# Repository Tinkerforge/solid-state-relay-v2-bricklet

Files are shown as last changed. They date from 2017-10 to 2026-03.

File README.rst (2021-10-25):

Solid State Relay Bricklet 2.0
==============================

This repository contains the firmware source code and the hardware design
files. The documentation generator configs can be found at
https://github.com/Tinkerforge/generators

Repository Content
------------------

software/:
 * examples/: Examples for all supported languages
 * build/: Compiled files
 * src/: Source code of firmware
 * Makefile: Makefile to build project

hardware/:
 * Contains KiCad project files and additionally schematics as PDF

datasheets/:
 * Contains datasheets for sensors and complex ICs that are used

Hardware
--------

The hardware is designed with the open source EDA Suite KiCad
(http://www.kicad.org). Before you are able to open the files,
you have to install the Tinkerforge kicad-libraries
(https://github.com/Tinkerforge/kicad-libraries). You can either clone
them directly in hardware/ or clone them in a separate folder and
symlink them into hardware/
(ln -s kicad_path/kicad-libraries project_path/hardware). After that you
can open the .pro file in hardware/ with KiCad and from there view and
modify the schematics and the PCB layout.

Software
--------

If you want to do your own Brick/Bricklet firmware development we highly
recommend that you use our build environment setup script and read the
tutorial (https://www.tinkerforge.com/en/doc/Tutorials/Tutorial_Build_Environment/Tutorial.html).

To compile the C code we recommend you to install the newest GNU Arm Embedded
Toolchain (https://launchpad.net/gcc-arm-embedded/+download).
You also need to install bricklib2 (https://github.com/Tinkerforge/bricklib2).

You can either clone it directly in software/src/ or clone it in a
separate folder and symlink it into software/src/
(ln -s bricklib_path/bricklib2 project_path/software/src/). Finally make sure to
have CMake installed (http://www.cmake.org/cmake/resources/software.html).

After that you can build the firmware by invoking make in software/.
The firmware (.zbin) can then be found in software/build/ and uploaded
with brickv (click button "Flashing" on start screen).

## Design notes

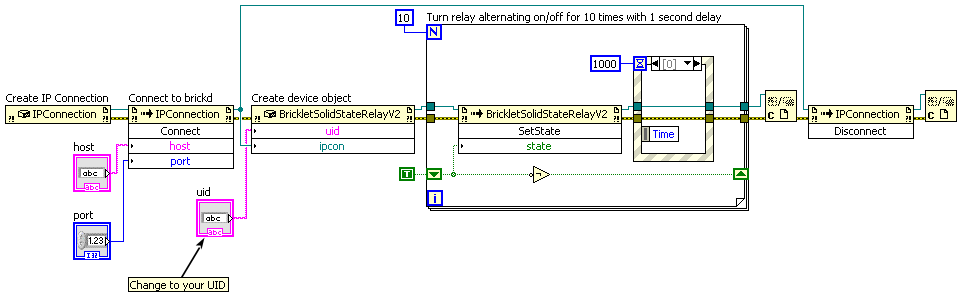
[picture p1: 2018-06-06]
software/examples/labview/Example Simple.vi.png

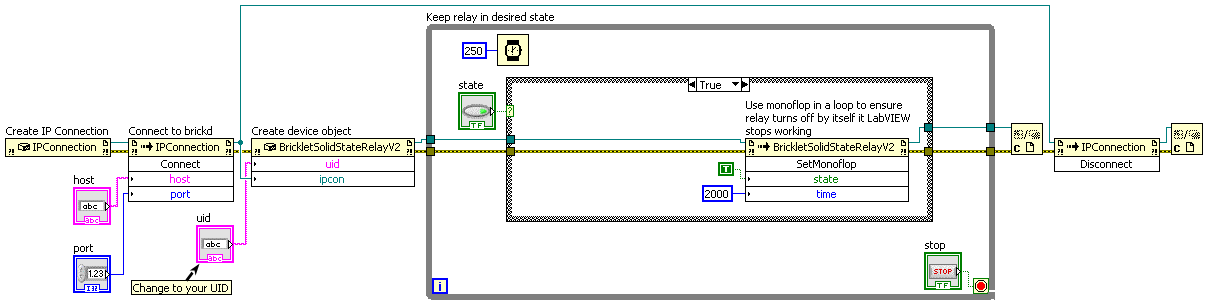
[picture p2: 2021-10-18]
software/examples/labview/Example Monoflop.vi.png

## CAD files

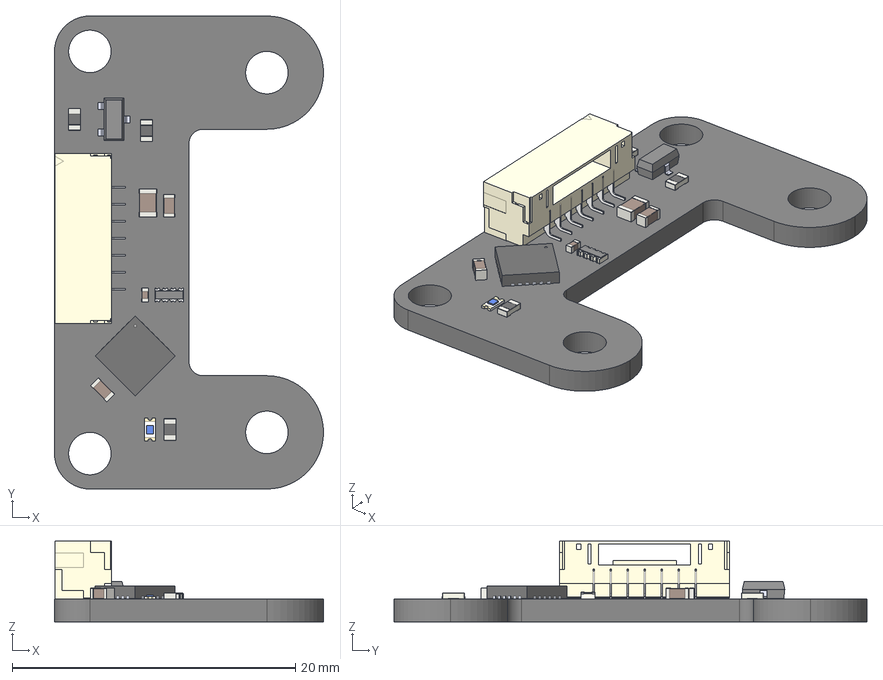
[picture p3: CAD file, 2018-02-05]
hardware/solid-state-relay-v2.step
19.0 x 33.4 x 5.70 mm

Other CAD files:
hardware/solid-state-relay-v2.FCStd

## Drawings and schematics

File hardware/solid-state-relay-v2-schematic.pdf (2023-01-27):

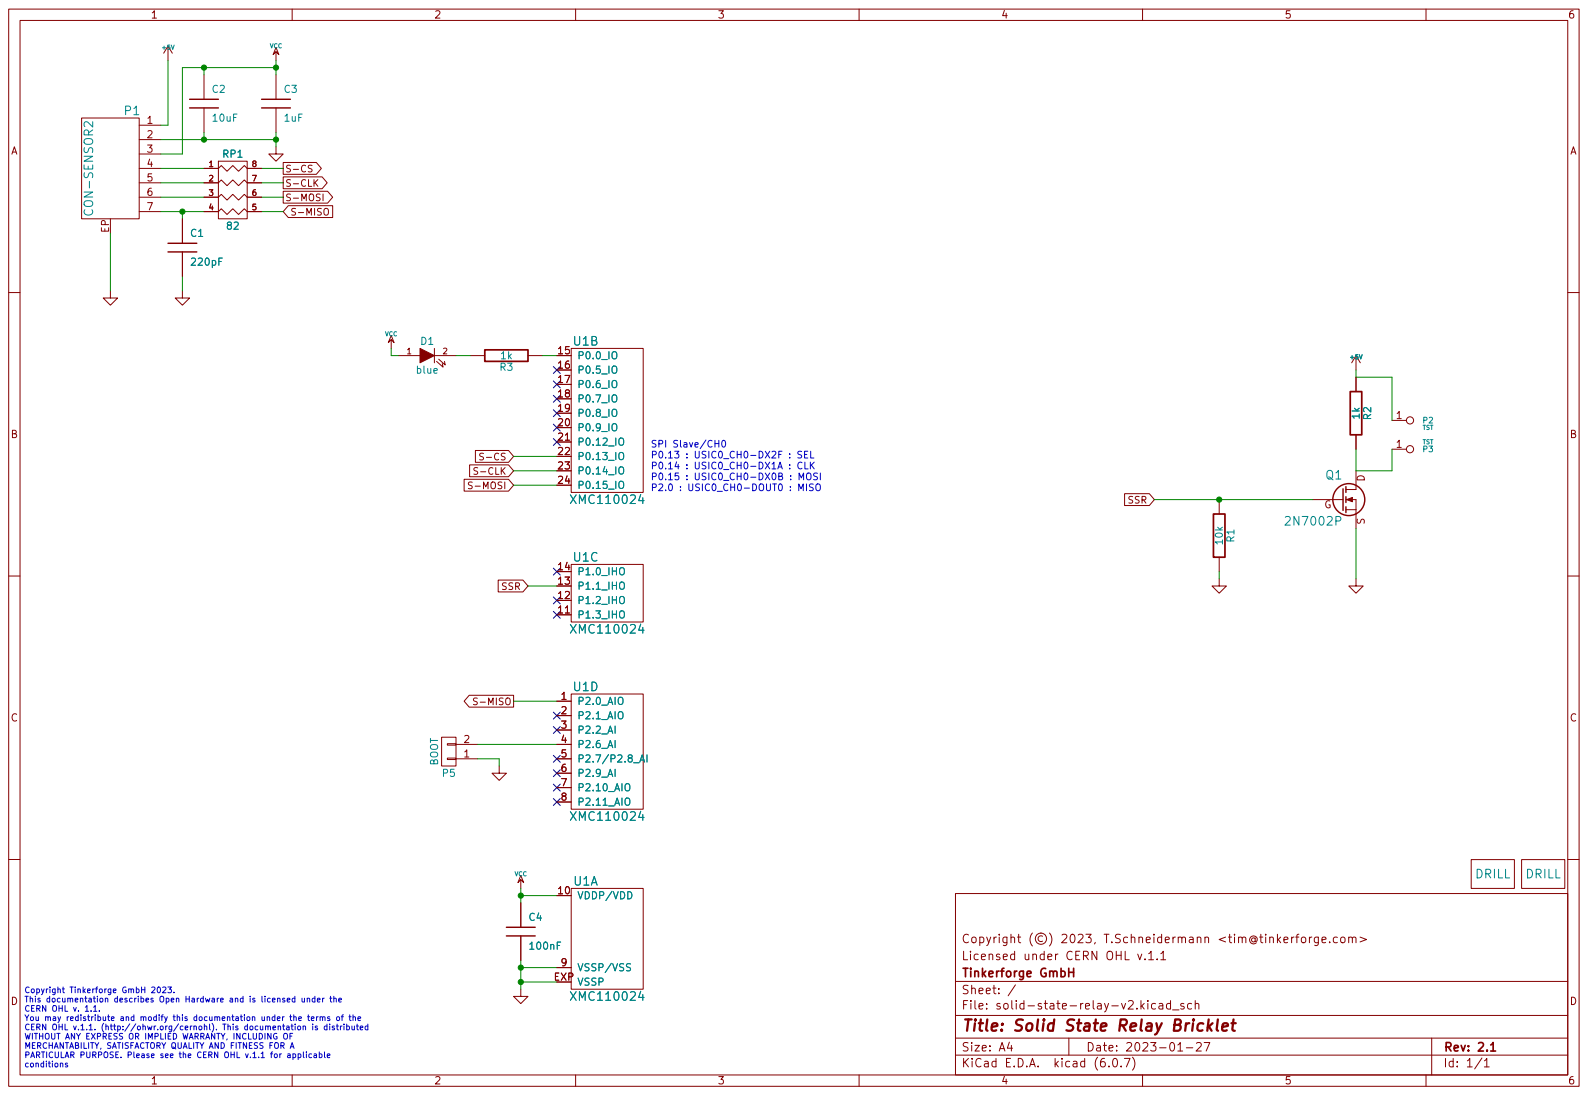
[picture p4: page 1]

SPI Slave/CH0 P0.13 : USIC0_CH0-DX2F : SEL P0.14 : USIC0_CH0-DX1A : CLK

Licensed under CERN OHL v.1.1
File: solid-state-relay-v2.kicad_sch Sheet: / Tinkerforge GmbH

Copyright Tinkerforge GmbH 2023. This documentation describes Open Hardware and is licensed under the CERN OHL v. 1.1. You may redistribute and modify this documentation under the terms of the CERN OHL v.1.1. (http://ohwr.org/cernohl). This documentation is distributed WITHOUT ANY EXPRESS OR IMPLIED WARRANTY, INCLUDING OF MERCHANTABILITY, SATISFACTORY QUALITY AND FITNESS FOR A

Id: 1/1 Title: Solid State Relay Bricklet

PARTICULAR PURPOSE. Please see the CERN OHL v.1.1 for applicable

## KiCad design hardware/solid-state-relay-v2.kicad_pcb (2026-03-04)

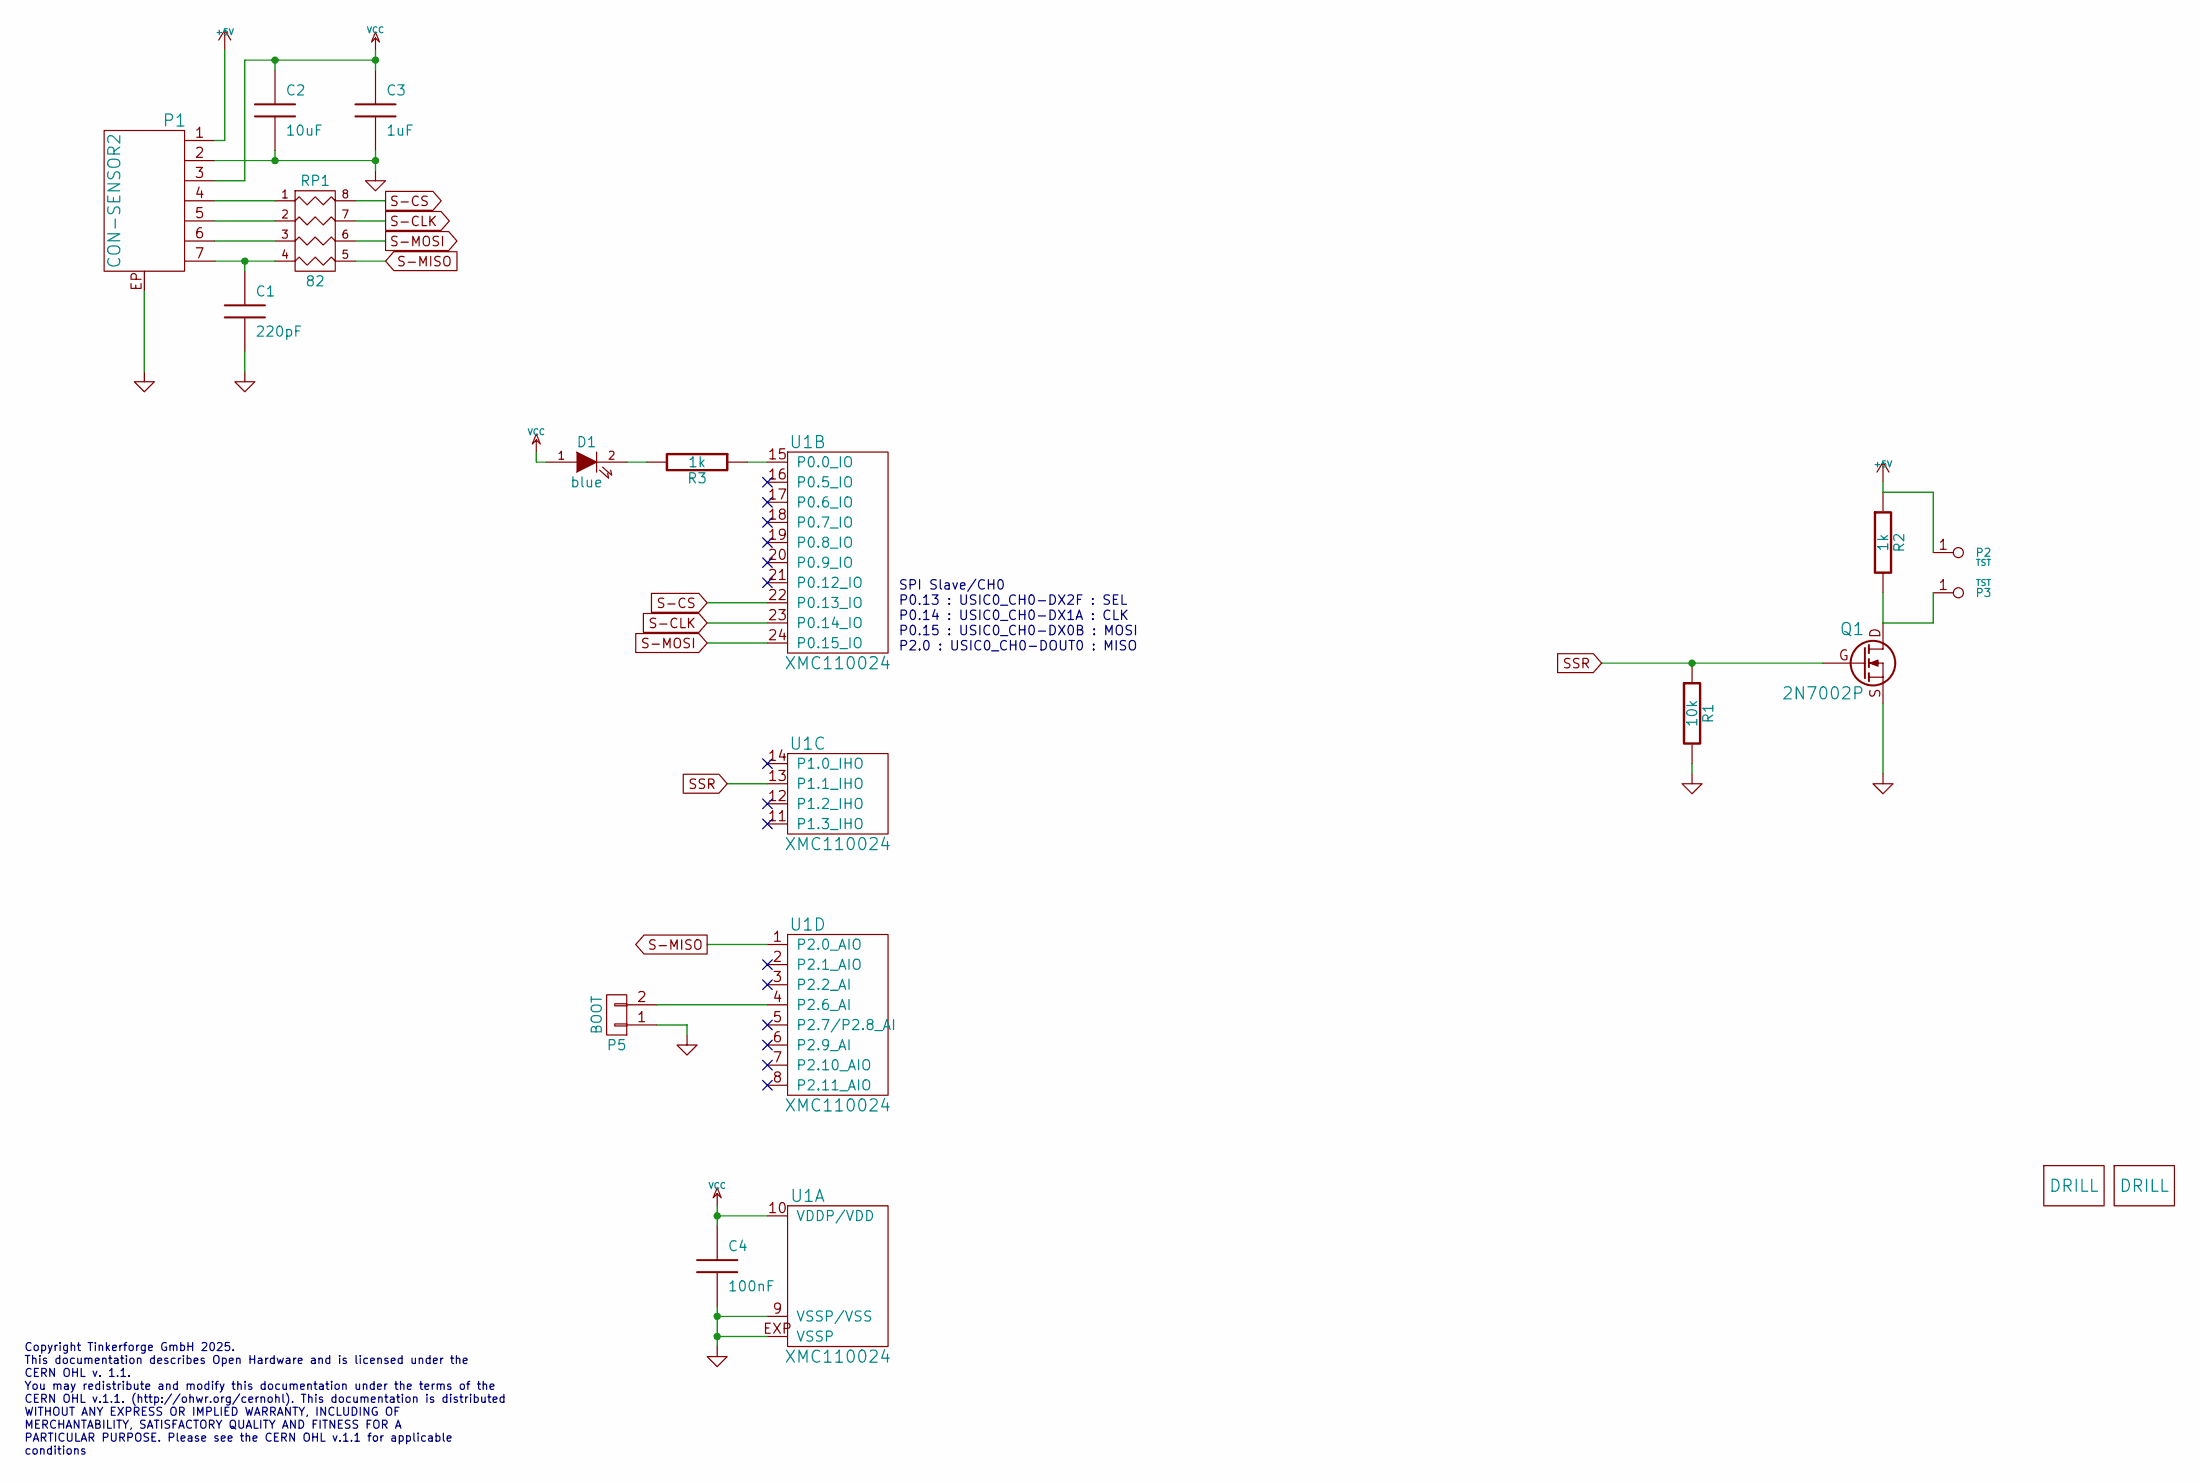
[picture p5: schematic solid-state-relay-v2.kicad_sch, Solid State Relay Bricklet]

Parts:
C1: 220pF; C0402F
C2: 10uF; C0805
C3: 1uF; C0603F
C4: 100nF; C0603F
D1: blue; D0603F
P1: CON-SENSOR2
P2, P3: TST; Drill
P5: BOOT; SolderJumper
Q1: 2N7002P; SOT23GDS
R1: 10k; R0603F
R2, R3: 1k; R0603F
RP1: 82; 4X0402
U1: XMC110024; QFN24-4x4mm-0.5mm
U2, U3: DRILL; DRILL_NP

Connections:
+5V: P1.1, P2.1, R2.1
GND: C1.2, C2.2, C3.2, C4.2, P1.2, P1.EP, P5.1, Q1.S, R1.2, U1.9 (VSSP/VSS), U1.EXP (VSSP)
unnamed: C1.1, P1.7, RP1.4
unnamed: D1.2 (K), R3.2
unnamed: P1.4, RP1.1
unnamed: P1.5, RP1.2
unnamed: P1.6, RP1.3
unnamed: P5.2, U1.4 (P2.6_AI)
unnamed: P3.1, Q1.D, R2.2
unnamed: R3.1, U1.15 (P0.0_IO)
S-CLK: RP1.7 (R2), U1.23 (P0.14_IO)
S-CS: RP1.8 (R1), U1.22 (P0.13_IO)
S-MISO: RP1.5 (R4), U1.1 (P2.0_AIO)
S-MOSI: RP1.6 (R3), U1.24 (P0.15_IO)
SSR: Q1.G, R1.1, U1.13 (P1.1_IHO)
VCC: C2.1, C3.1, C4.1, D1.1 (A), P1.3, U1.10 (VDDP/VDD)

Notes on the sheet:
SPI Slave/CH0 P0.13 : USIC0_CH0-DX2F : SEL P0.14 : USIC0_CH0-DX1A : CLK P0.15 : USIC0_CH0-DX0B : MOSI P2.0 : USIC0_CH0-DOUT0 : MISO
Copyright Tinkerforge GmbH 2025. This documentation describes Open Hardware and is licensed under the CERN OHL v. 1.1. You may redistribute and modify this documentation under the terms of the CERN OHL v.1.1. (http://ohwr.org/cernohl). This documentation is distributed WITHOUT ANY EXPRESS OR IMPLIE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

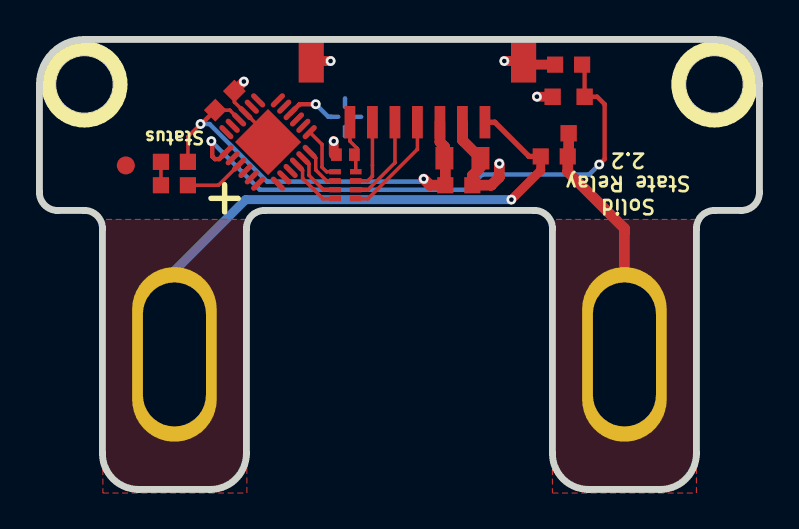
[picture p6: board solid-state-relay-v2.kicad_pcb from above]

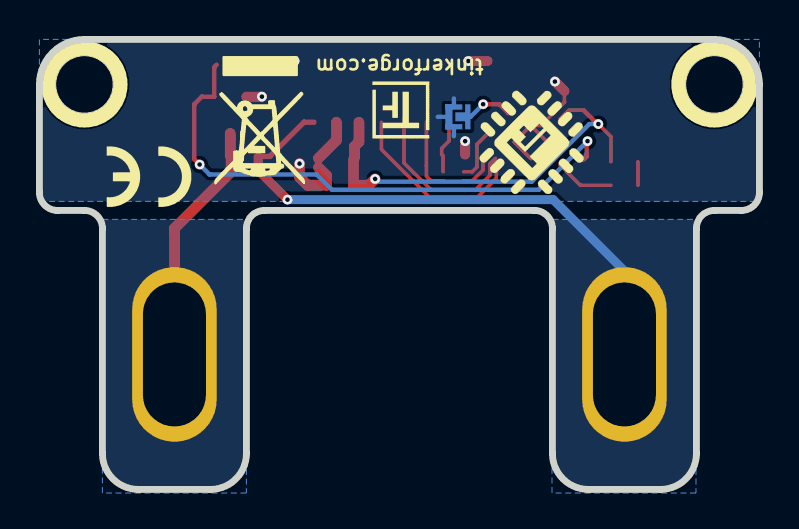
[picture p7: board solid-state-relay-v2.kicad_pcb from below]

Board: 2 copper layers, 40.0 x 25.0 mm, 20 parts (3 on the bottom side), 16 nets.

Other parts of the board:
Fiducial_Mark: VAL**; Fiducial_Mark
VAL: WEEE_7mm
VAL#2: CE_5mm

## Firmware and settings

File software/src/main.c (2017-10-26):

/* solid-state-relay-v2-bricklet
 * Copyright (C) 2017 Olaf Lüke <olaf@tinkerforge.com>
 *
 * main.c: Initialization for Solid State Relay V2 Bricklet
 *
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
 * You should have received a copy of the GNU Lesser General Public
 * License along with this library; if not, write to the
 * Free Software Foundation, Inc., 59 Temple Place - Suite 330,
 * Boston, MA 02111-1307, USA.
 */

#include <stdio.h>
#include <stdbool.h>

#include "configs/config.h"

#include "bricklib2/bootloader/bootloader.h"
#include "bricklib2/hal/system_timer/system_timer.h"
#include "bricklib2/logging/logging.h"
#include "communication.h"
#include "relay.h"

int main(void) {
	logging_init();
	logd("Start Solid State Relay V2 Bricklet\n\r");

	communication_init();
	relay_init();

	while(true) {
		bootloader_tick();
		communication_tick();
		relay_tick();
	}
}

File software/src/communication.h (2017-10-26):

/* solid-state-relay-v2-bricklet
 * Copyright (C) 2017 Olaf Lüke <olaf@tinkerforge.com>
 *
 * communication.h: TFP protocol message handling
 *
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
 * You should have received a copy of the GNU Lesser General Public
 * License along with this library; if not, write to the
 * Free Software Foundation, Inc., 59 Temple Place - Suite 330,
 * Boston, MA 02111-1307, USA.
 */

#ifndef COMMUNICATION_H
#define COMMUNICATION_H

#include <stdint.h>
#include <stdbool.h>

#include "bricklib2/protocols/tfp/tfp.h"
#include "bricklib2/bootloader/bootloader.h"

// Default functions
BootloaderHandleMessageResponse handle_message(const void *data, void *response);
void communication_tick(void);
void communication_init(void);

// Constants
#define SOLID_STATE_RELAY_V2_BOOTLOADER_MODE_BOOTLOADER 0
#define SOLID_STATE_RELAY_V2_BOOTLOADER_MODE_FIRMWARE 1
#define SOLID_STATE_RELAY_V2_BOOTLOADER_MODE_BOOTLOADER_WAIT_FOR_REBOOT 2
#define SOLID_STATE_RELAY_V2_BOOTLOADER_MODE_FIRMWARE_WAIT_FOR_REBOOT 3
#define SOLID_STATE_RELAY_V2_BOOTLOADER_MODE_FIRMWARE_WAIT_FOR_ERASE_AND_REBOOT 4

#define SOLID_STATE_RELAY_V2_BOOTLOADER_STATUS_OK 0
#define SOLID_STATE_RELAY_V2_BOOTLOADER_STATUS_INVALID_MODE 1
#define SOLID_STATE_RELAY_V2_BOOTLOADER_STATUS_NO_CHANGE 2
#define SOLID_STATE_RELAY_V2_BOOTLOADER_STATUS_ENTRY_FUNCTION_NOT_PRESENT 3
#define SOLID_STATE_RELAY_V2_BOOTLOADER_STATUS_DEVICE_IDENTIFIER_INCORRECT 4
#define SOLID_STATE_RELAY_V2_BOOTLOADER_STATUS_CRC_MISMATCH 5

#define SOLID_STATE_RELAY_V2_STATUS_LED_CONFIG_OFF 0
#define SOLID_STATE_RELAY_V2_STATUS_LED_CONFIG_ON 1
#define SOLID_STATE_RELAY_V2_STATUS_LED_CONFIG_SHOW_HEARTBEAT 2
#define SOLID_STATE_RELAY_V2_STATUS_LED_CONFIG_SHOW_STATUS 3

// Function and callback IDs and structs
#define FID_SET_STATE 1
#define FID_GET_STATE 2
#define FID_SET_MONOFLOP 3
#define FID_GET_MONOFLOP 4

#define FID_CALLBACK_MONOFLOP_DONE 5

typedef struct {
	TFPMessageHeader header;
	bool state;
} __attribute__((__packed__)) SetState;

typedef struct {
	TFPMessageHeader header;
} __attribute__((__packed__)) GetState;

typedef struct {
	TFPMessageHeader header;
	bool state;
} __attribute__((__packed__)) GetState_Response;

typedef struct {
	TFPMessageHeader header;
	bool state;
	uint32_t time;
} __attribute__((__packed__)) SetMonoflop;

typedef struct {
	TFPMessageHeader header;
} __attribute__((__packed__)) GetMonoflop;

typedef struct {
	TFPMessageHeader header;
	bool state;
	uint32_t time;
	uint32_t time_remaining;
} __attribute__((__packed__)) GetMonoflop_Response;

typedef struct {
	TFPMessageHeader header;
	bool state;
} __attribute__((__packed__)) MonoflopDone_Callback;


// Function prototypes
BootloaderHandleMessageResponse set_state(const SetState *data);
BootloaderHandleMessageResponse get_state(const GetState *data, GetState_Response *response);
BootloaderHandleMessageResponse set_monoflop(const SetMonoflop *data);
BootloaderHandleMessageResponse get_monoflop(const GetMonoflop *data, GetMonoflop_Response *response);

// Callbacks
bool handle_monoflop_done_callback(void);

#define COMMUNICATION_CALLBACK_TICK_WAIT_MS 1
#define COMMUNICATION_CALLBACK_HANDLER_NUM 1
#define COMMUNICATION_CALLBACK_LIST_INIT \
	handle_monoflop_done_callback, \


#endif

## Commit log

2017-09-18 Add schematic
    [solid_state_relay.sch]
2017-09-18 Fix footprints, optical adjustments
    [solid_state_relay.sch]
2017-09-18 Finished prototype
    [solid_state_relay.kicad_pcb, solid_state_relay.sch]
2017-09-18 Fix outlines
    [solid_state_relay.kicad_pcb]
2017-09-18 Fix conductor paths
    [solid_state_relay.kicad_pcb]
2017-10-13 Add initial stub implementation
    [cmake_config_custom.txt]
2017-10-13 Add "status" marking for status LED
    [solid_state_relay.kicad_pcb]
2017-10-19 fix outline edge cuts layer, fix weee logo
    [solid_state_relay.kicad_pcb]
2017-10-23 Add 3d model (*.step & *.FCStd)
    [solid_state_relay.FCStd, solid_state_relay.step]
2017-10-26 change led position
    [solid_state_relay.kicad_pcb]
2017-10-26 Implement relay set/get functionality
2017-10-26 specify processor type
    [solid_state_relay.kicad_pcb, solid_state_relay.sch]
2018-02-05 Update 3d model
    [solid_state_relay.FCStd, solid_state_relay.step]
2018-02-16 Add schematic (PDF)
2018-02-20 Cleanup KiCad libraries config
    Ensure LibDir=kicad-libraries and LibName1=tinkerforge.
    Remove special library.
2018-05-11 Rename files
    [solid-state-relay-v2.FCStd, solid-state-relay-v2.kicad_pcb, solid-state-relay-v2.sch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]
2018-06-18 Change capacitor footprint(s) to C0402F
    [solid-state-relay-v2.kicad_pcb, solid-state-relay-v2.sch]
2019-05-07 Make get-monoflop always return the current state to match documentation
2020-09-02 uc: Add example driver note.
2021-10-25 Update KiCad link
    https://www.kicad.org/blog/2021/10/Avoid-links-to-former-kicad-domain/
2022-04-27 uc: Adapt to bindings changes
    [example_simple.c]
2023-01-23 New standart layout. Switched to Kicad 6
    [solid-state-relay-v2.kicad_pcb, solid-state-relay-v2.kicad_sch, solid-state-relay-v2.sch]
2023-01-27 fix schematic library
    [solid-state-relay-v2.kicad_sch]
2023-01-27 Hardware 2.1: Made Pcb bigger to fit on the 40mm grid. Data Cleanup
    [solid-state-relay-v2.kicad_pcb, solid-state-relay-v2.kicad_sch]
2025-05-20 version 2.2: add slotted holes
    [solid-state-relay-v2.kicad_pcb, solid-state-relay-v2.kicad_sch]
2026-03-04 adapt outline to 5mm grid
    [solid-state-relay-v2.kicad_pcb]
2026-03-04 small dimensions changes
    [solid-state-relay-v2.kicad_pcb]
2026-03-04 fix layers
    [solid-state-relay-v2.kicad_pcb]

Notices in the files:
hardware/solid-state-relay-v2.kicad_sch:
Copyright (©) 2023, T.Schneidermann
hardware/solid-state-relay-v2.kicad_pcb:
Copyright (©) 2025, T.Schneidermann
